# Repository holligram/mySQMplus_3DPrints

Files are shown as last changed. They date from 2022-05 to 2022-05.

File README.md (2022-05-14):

# mySQM+ 3DPrints

Unofficial 3D prints designed to work with the [mySQM+ DIY SQM WEATHER STATION](https://sourceforge.net/projects/mysqmproesp32/files) project by Robert Brown.

These prints will be installed outdoors to monitor weather and will be subjected to the elements over time. The recommend material for 3D printing is ASA or PETG, both of which are insensitive to changing temperature and are resistant to UV rays. The UV resistance is key to choosing one of these materials. 

## Anemometer

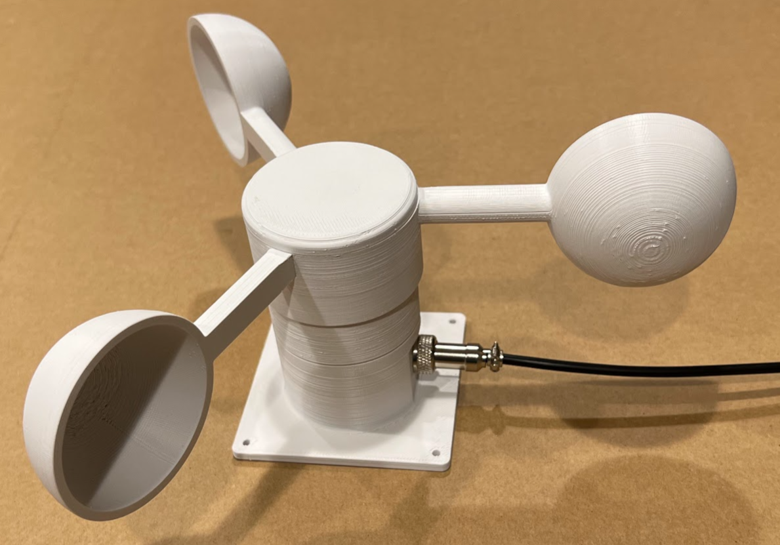
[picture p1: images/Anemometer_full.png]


[More Info on the Anemometer](3D%20Prints%20(STL)/Anemometer)

## Wind Vane

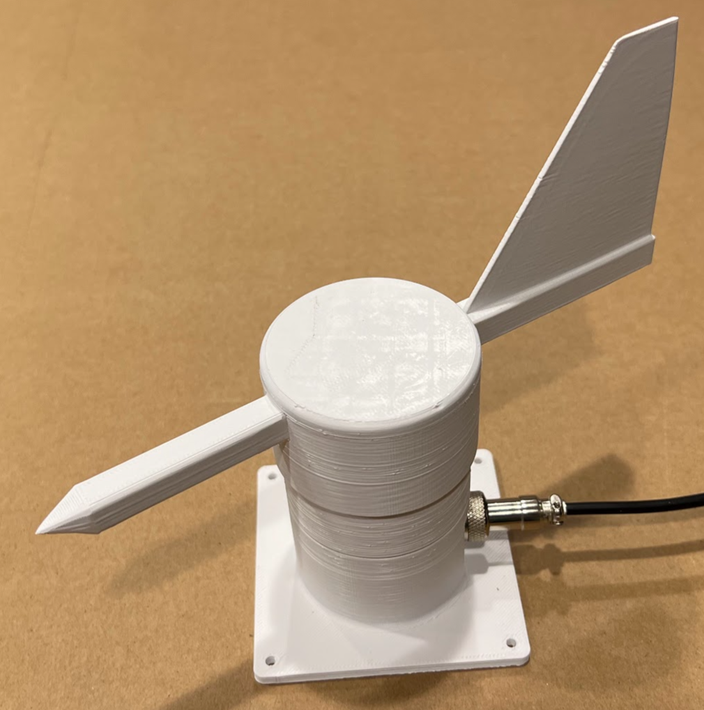
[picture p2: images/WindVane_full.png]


[More Info on the Wind Vane](3D%20Prints%20(STL)/Wind%20Vane)

## About

BY: Graham Hollis [holligram](https://github.com/holligram)

LICENSE: Creative Commons Zero v1.0 Universal

ATTRIBUTE: This is a redesign of the mySQM+ 3D prints created by Robert Brown for his mySQM+ DIY SQM WEATHER STATION project found on Sourceforge at the link https://sourceforge.net/projects/mysqmproesp32/files

Incorporating the threaded joint idea from the rework of Robert Brown's anemometer design that was made by [CBaker007](https://github.com/CBaker007/mySQM-3D_Anemometer/)

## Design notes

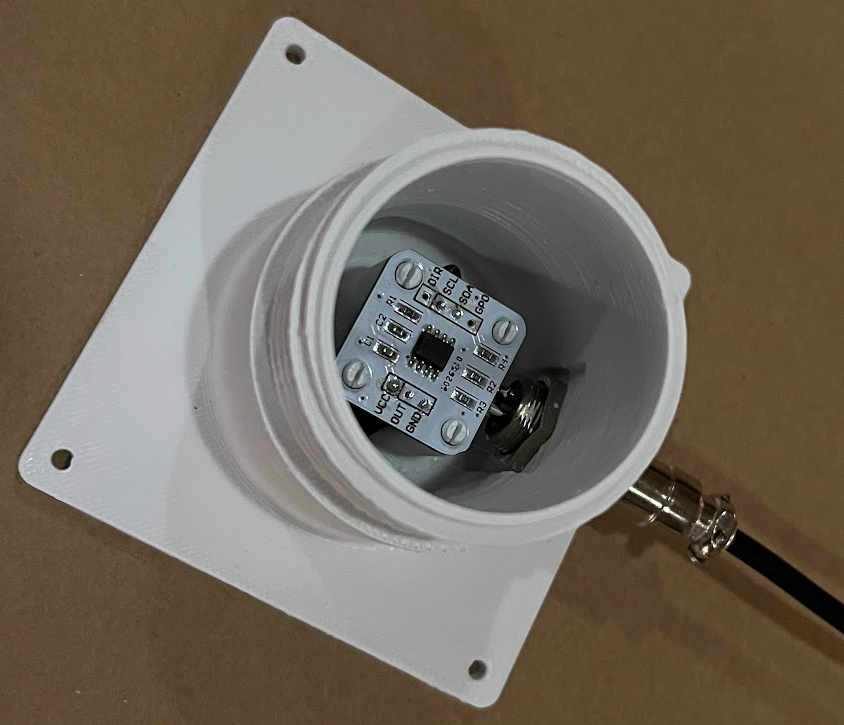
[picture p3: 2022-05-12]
images/WindVane_base.png

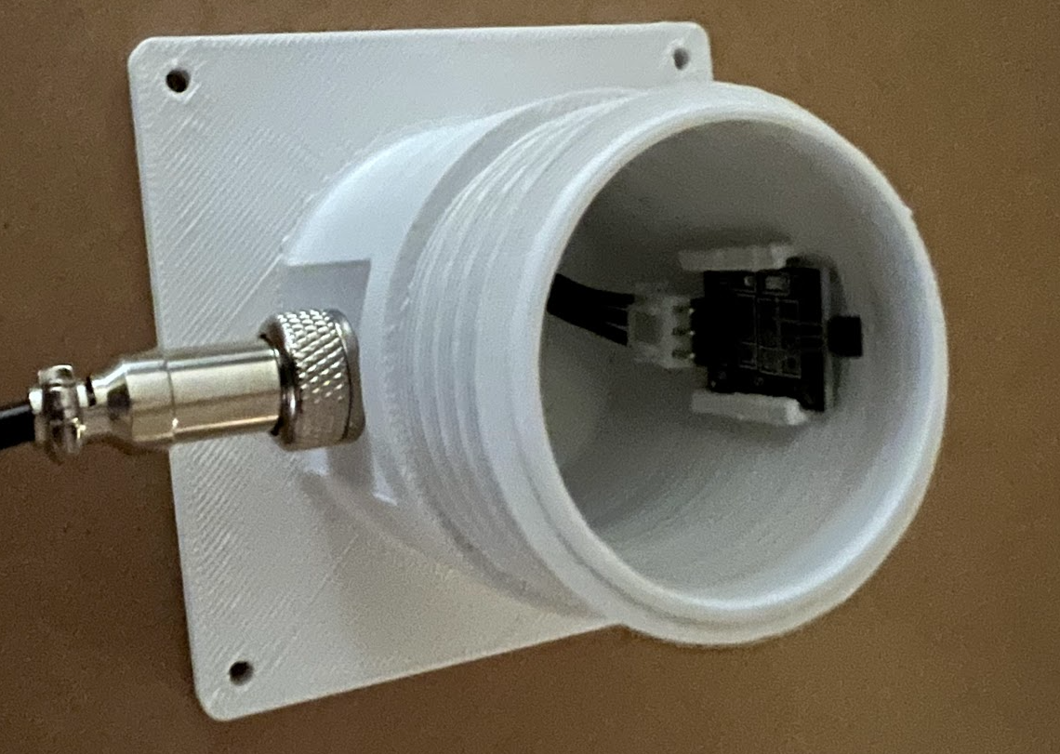
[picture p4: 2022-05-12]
images/Anemometer_base.png

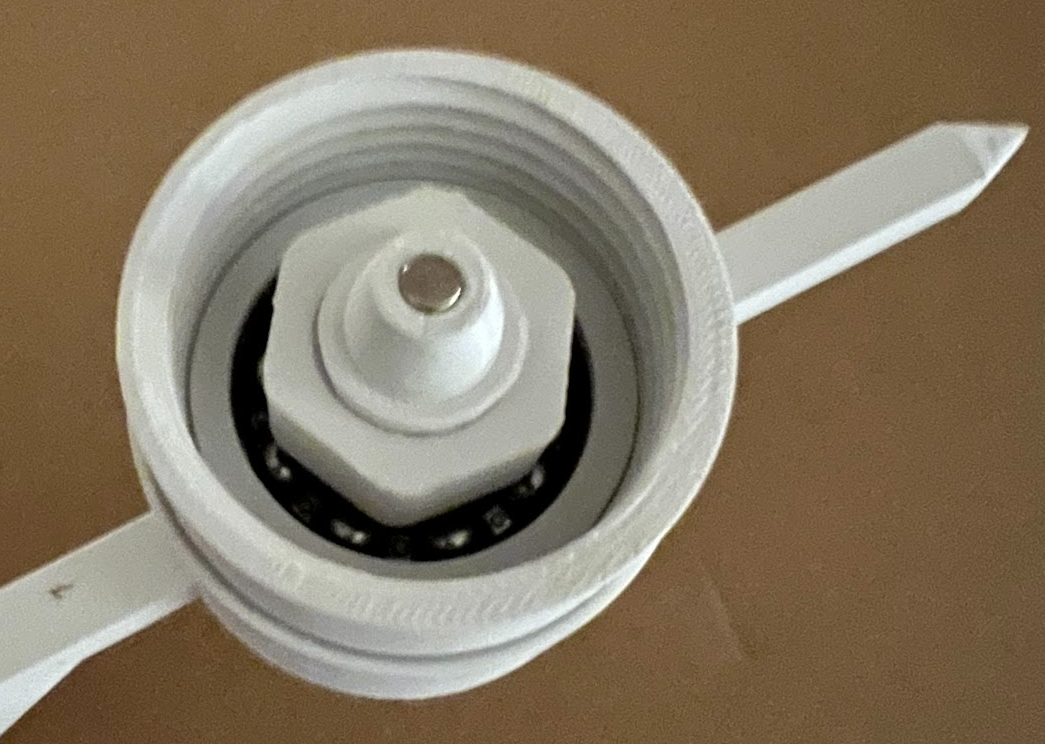
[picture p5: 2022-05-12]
images/WindVane_top.png

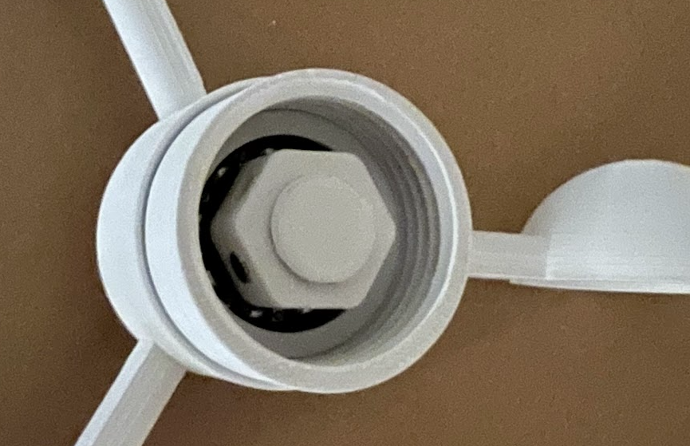
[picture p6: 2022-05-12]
images/Anemometer_top.png

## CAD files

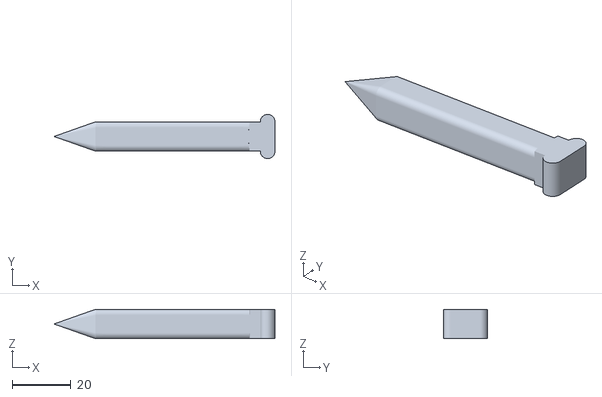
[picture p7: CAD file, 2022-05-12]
3D Prints (STL)/Wind Vane/Pointer.stl
75.0 x 15.0 x 10.0

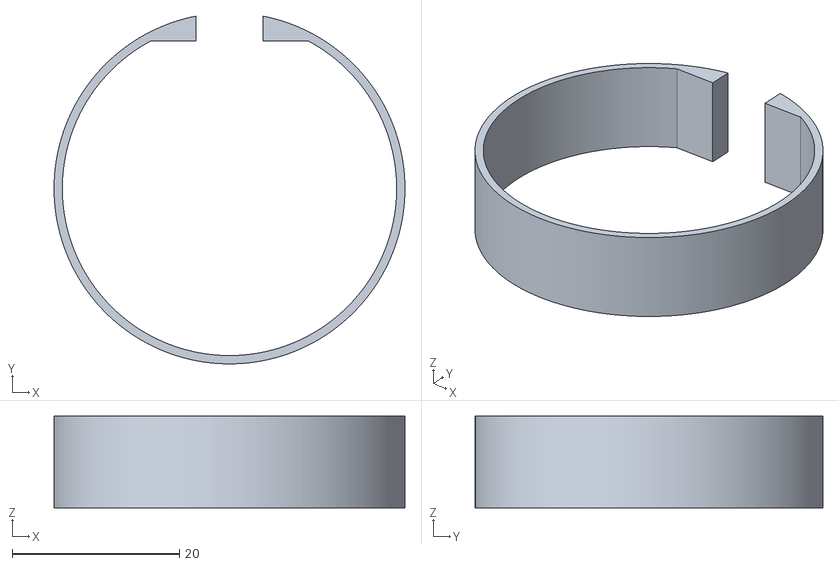
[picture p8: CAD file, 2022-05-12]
3D Prints (STL)/Anemometer/Board Retainer.stl
42.0 x 41.6 x 11.0

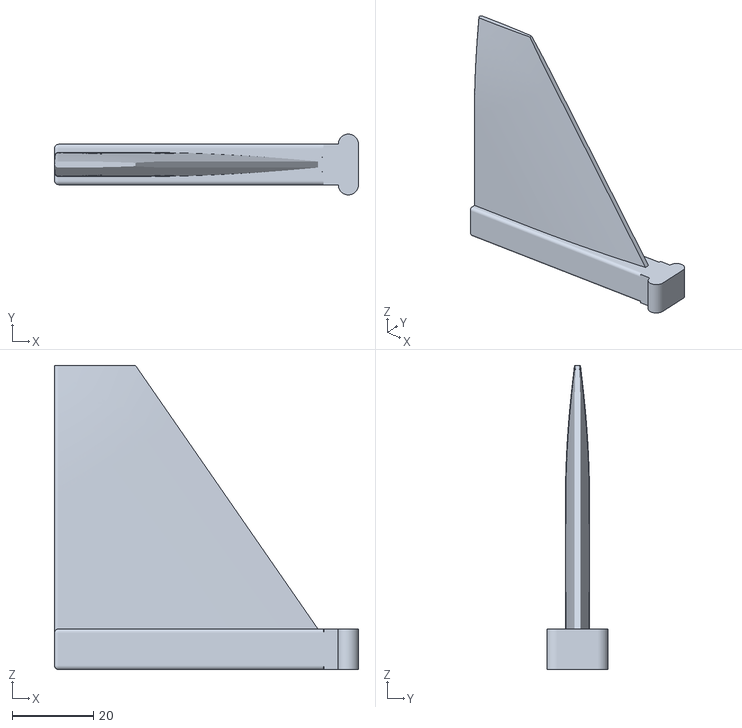
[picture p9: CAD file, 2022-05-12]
3D Prints (STL)/Wind Vane/Tail.stl
75.0 x 15.0 x 75.0

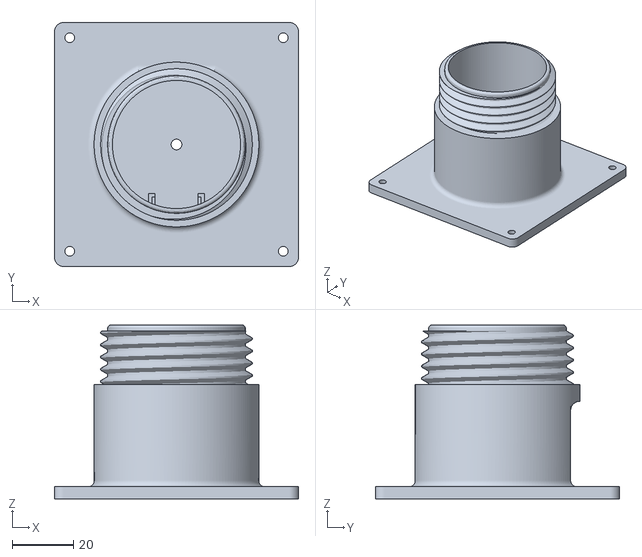
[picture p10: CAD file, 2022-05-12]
3D Prints (STL)/Anemometer/Base_KY-003.stl
80.0 x 80.0 x 57.0

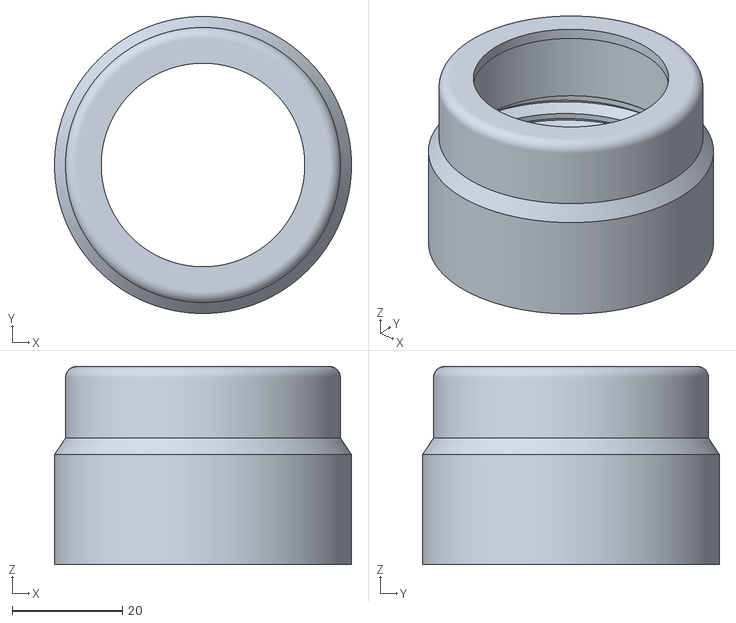
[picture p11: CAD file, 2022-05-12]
3D Prints (STL)/Wind Vane/Bearing Housing.stl
54.0 x 54.0 x 36.0

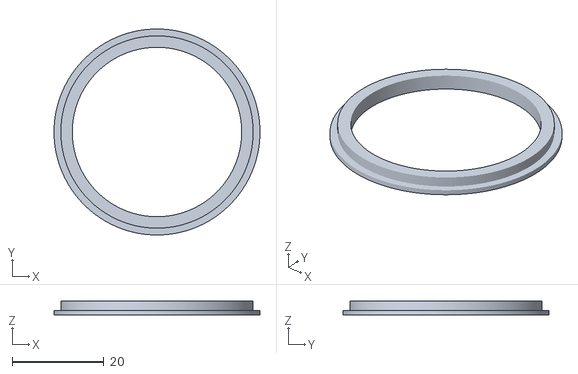
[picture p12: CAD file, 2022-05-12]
3D Prints (STL)/Anemometer/Bearing Retainer.stl
45.0 x 45.0 x 3.00

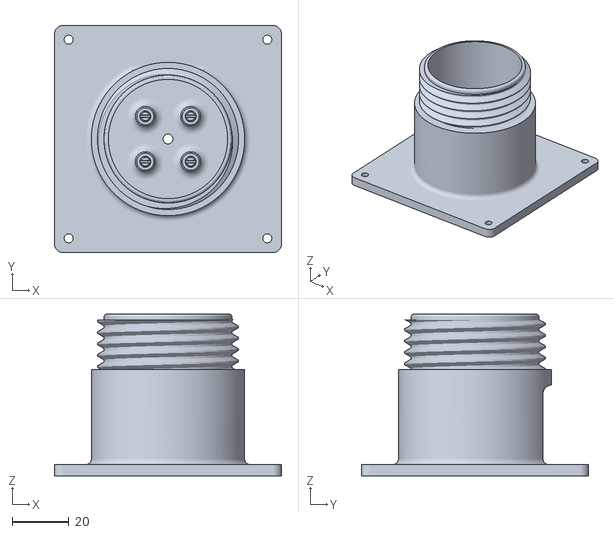
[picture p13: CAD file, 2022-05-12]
3D Prints (STL)/Wind Vane/Base.stl
80.0 x 80.0 x 57.0

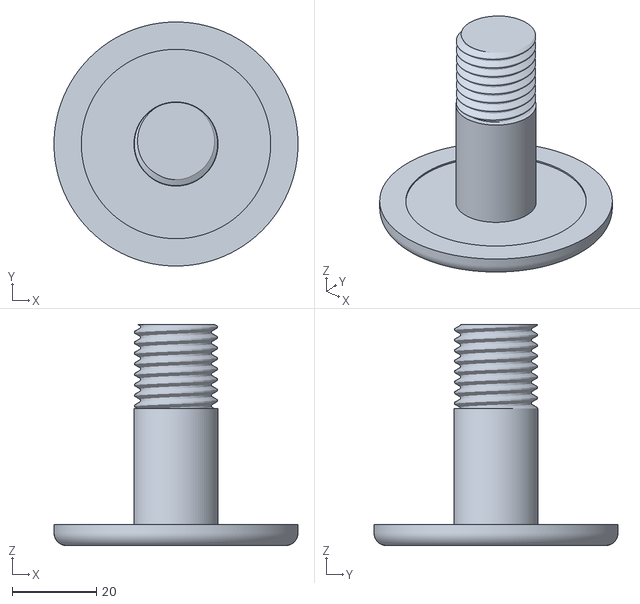
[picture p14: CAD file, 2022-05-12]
3D Prints (STL)/Anemometer/Cap.stl
58.0 x 58.0 x 52.6

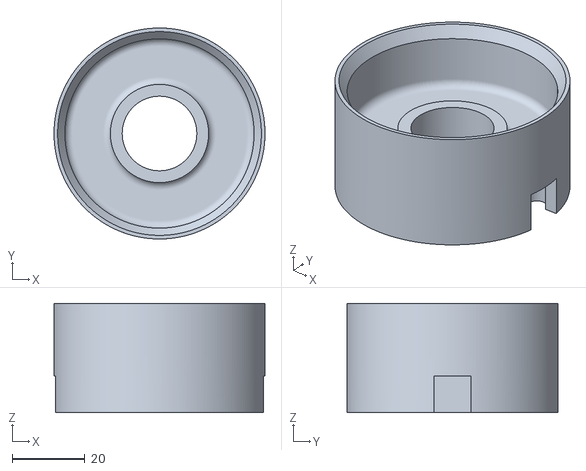
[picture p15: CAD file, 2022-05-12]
3D Prints (STL)/Wind Vane/Hub.stl
58.0 x 58.0 x 30.0

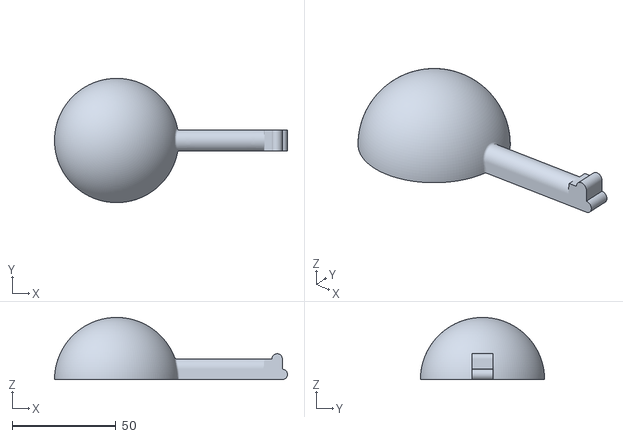
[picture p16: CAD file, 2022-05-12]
3D Prints (STL)/Anemometer/Arm.stl
112.5 x 60.0 x 30.0

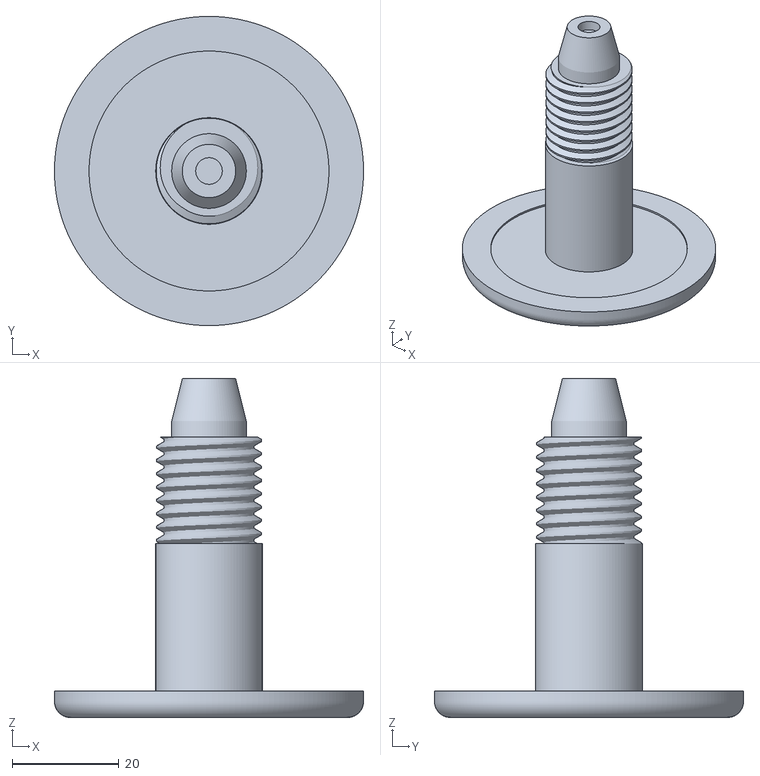
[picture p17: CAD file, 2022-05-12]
3D Prints (STL)/Wind Vane/Cap.stl
58.0 x 58.0 x 63.6

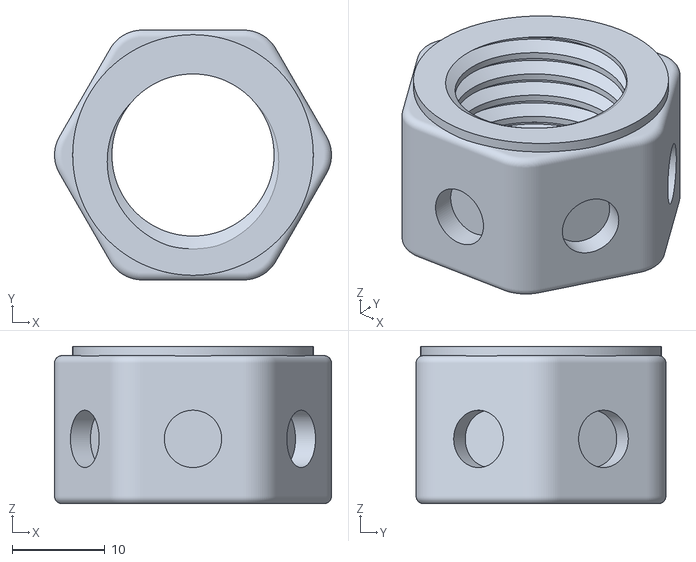
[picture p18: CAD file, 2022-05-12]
3D Prints (STL)/Anemometer/Nut.stl
29.9 x 27.0 x 17.0

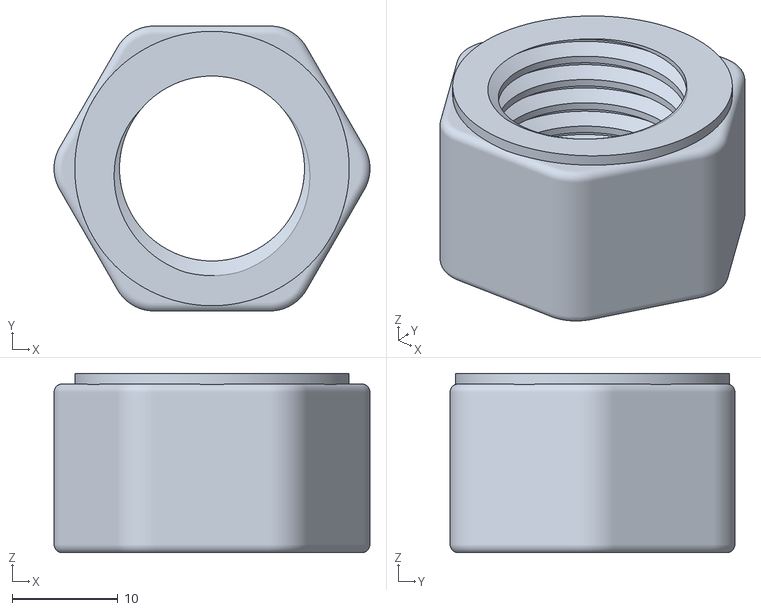
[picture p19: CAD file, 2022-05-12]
3D Prints (STL)/Wind Vane/Nut.stl
29.9 x 27.0 x 17.0

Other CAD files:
3D Prints (STL)/Anemometer/Base_KY-024.stl
3D Prints (STL)/Wind Vane/Retainer.stl
3D Prints (STL)/Anemometer/Bearing Housing.stl
3D Prints (STL)/Anemometer/Hub.stl
CAD (Fusion)/Anemometer.f3d
CAD (Fusion)/Wind Vane.f3d

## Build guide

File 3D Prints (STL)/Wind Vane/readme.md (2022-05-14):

## Wind Vane

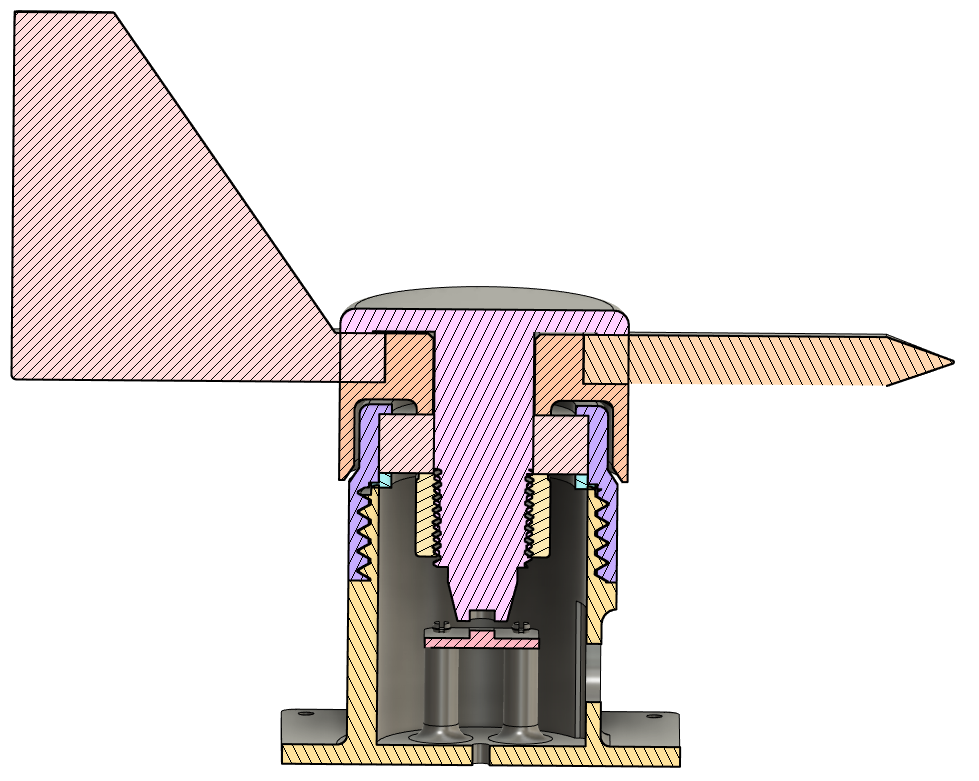
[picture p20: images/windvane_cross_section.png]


### Features

* A key feature of this design is that it does not use any metal fasteners to assemble. There are four 3d printed threads that are integral to the design and make for a secure assembly. As these are functional prints, they all should be printed with a maximum layer height of 0.2mm, 4 walls in and out, as well as 4 top and bottom layers.
* The sensor used is the AS5600 magnetic angle sensor. The bottom of base has four pinch pins that secure the sensor in place. Once assembled, the sensor will be at the correct height just below the magnet.

### Bill of Materials
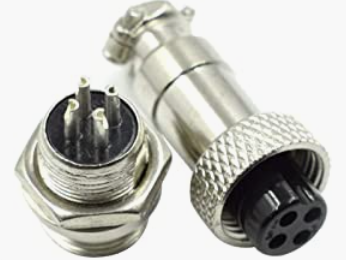
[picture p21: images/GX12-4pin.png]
-  4 pin Aviation type (GX12) connectors 
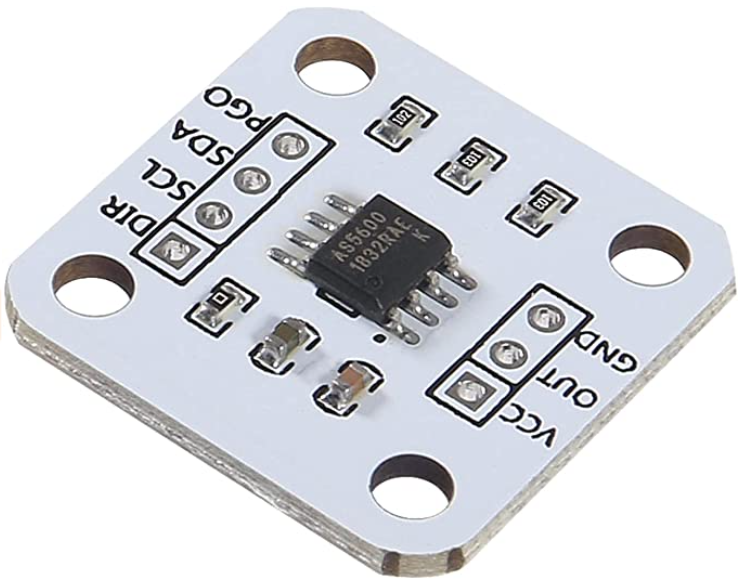
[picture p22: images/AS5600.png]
- AS5600 magnetic angle sensor with magnet.
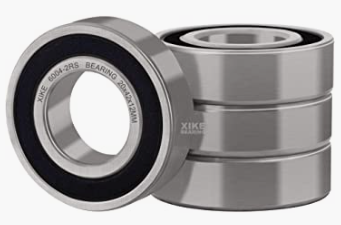
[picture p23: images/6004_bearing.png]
- 6004 bearing 20x42x12mm 

### Notes
- The common 6x3mm project magnet is too strong for this sensor and may overpower it causing unreliable data. I recommend using the smaller magnet provided with the sensor.
- Be sure the magnet is securely held in the provided cavity of the cap. Should it drop out and fall on the sensor below it, it may cause the magic smoke to escape the ESP32. Ask me how I know this!
- The pointer and tail are a tight fit in the hub which are then held fast by the cap. There may need some gentle filing to get them to fit correctly into the hub depending on how accurate your 3D printer is and how much over extrusion you have.
- The 3D printed threads may need to touched up with a file depending on how well your printer reproduces these.
- Prepare the bearing by removing and discarding the seals on both sides. You can pry underneath the plastic and lift them off. You will then need to wash out all the factory grease using a solvent. Once all the grease has been dissolved, it's dry and spins freely, lubricate with one drop of light machine oil.

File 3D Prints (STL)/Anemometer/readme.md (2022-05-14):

## Anemometer

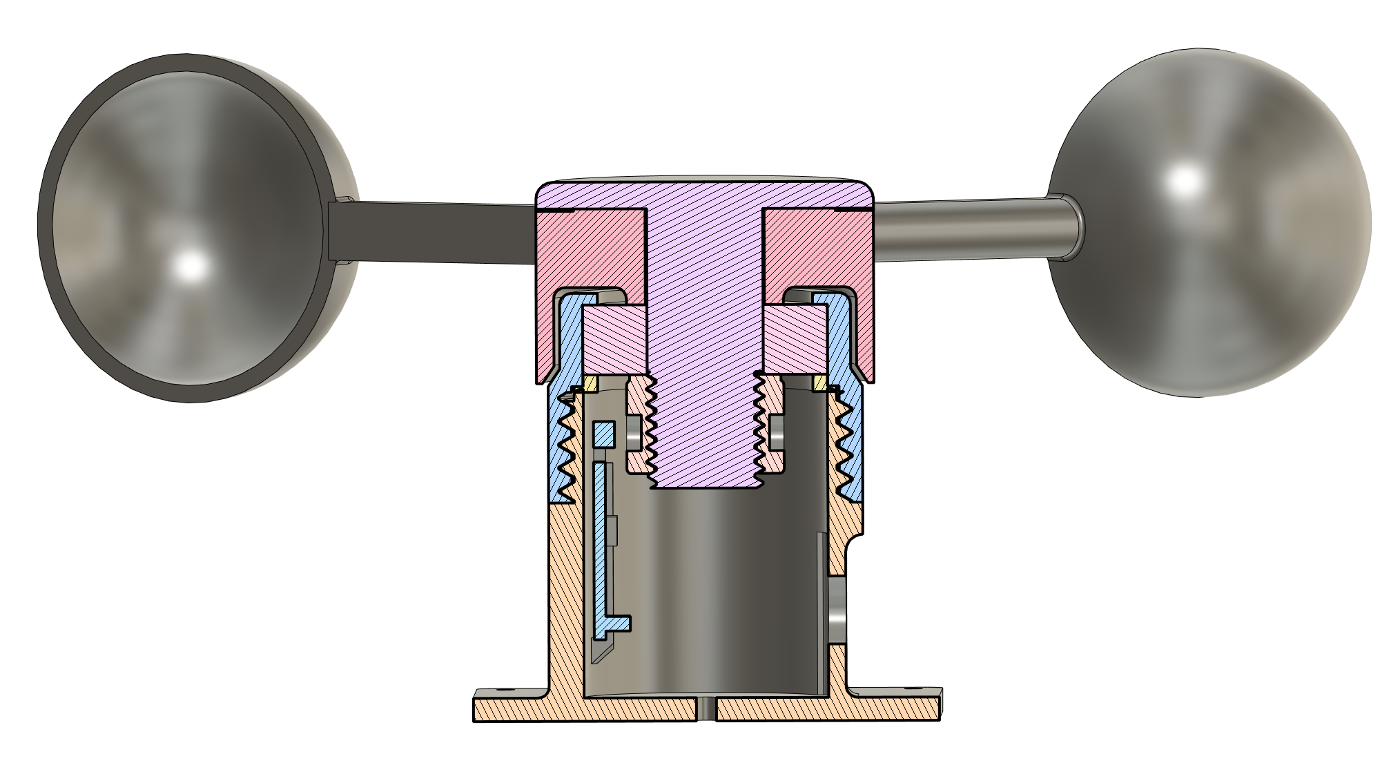
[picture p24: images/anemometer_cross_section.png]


### Features

* A key feature of this design is that it does not use any metal fasteners to assemble. There are four 3d printed threads that are integral to the design and make for a secure assembly. As these are functional prints, they all should be printed with a maximum layer height of 0.2mm, 4 walls in and out, as well as 4 top and bottom layers.

* The Anemometer design has an arm length of 100mm from the center of the hub to the middle of the cup. The mySQM+ mydefines.h will need to be adjusted:

`#define ARM_LENGTH                  (0.100)`

* The sensor used is either the KY-024 or the KY-003. The base has a pocket to accommodate the sensor and which places the magnet hall sensor at the correct height to interact with the magnets, which are housed in the hub nut. There are two versions of the base stl's provided. Select the one that matches the sensor you plan to use.
* There is an optional board retainer ring which will keep the board securely held in the pocket.  
* The 3D printed nut doubles as the magnet carrier and can contain either 1, 2, 3, or 6 magnets. Two magnets are recommended. The number of pulses generated per revolution is based on 1 pulse per magnet. The mySQM+ mydefines.h will need to be adjusted based on the number of magnets you use:

`#define PULSES_PER_REVOLUTION       2`

### Bill of Materials
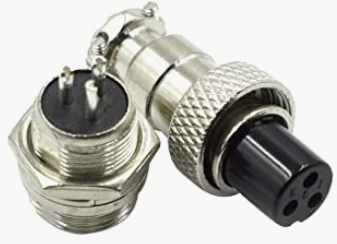
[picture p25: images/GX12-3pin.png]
-  3 pin Aviation type (GX12) connectors 
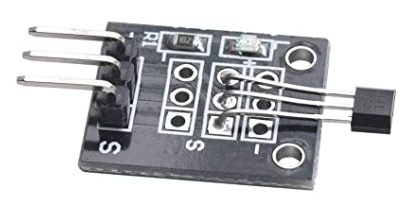
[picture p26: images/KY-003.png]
- KY-024 module <b>&nbsp;&nbsp;&nbsp;OR&nbsp;&nbsp;&nbsp;</b> KY-003 module
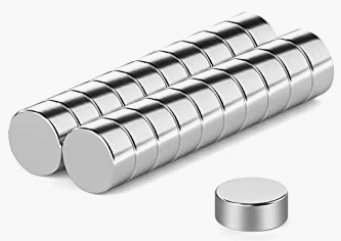
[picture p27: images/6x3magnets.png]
- 6mmx3mm magnets
- 6004 bearing 20x42x12mm 

### Notes
- I've tried both the KY-024 and the KY-003 module and was not able to get the KY-024 to work correctly.
- The KY-003 module works perfectly without the D2 or R3 components present in the circuit. Refer the mySQM+ documentation for more detail on this.
- The arms are a tight fit in the hub which are then held fast by the cap. The ends of the arms may need some filing to get them to fit into the hub depending on how accurate your 3D printer is and how much over extrusion you have.
- The 3D printed threads may need to touched up with a file depending on how well your printer reproduces these.
- Prepare the bearing by removing and discarding the seals on both sides. You can pry underneath the plastic and lift them off. You will then need to wash out all the factory grease using a solvent. Once all the grease has been dissolved, it's dry and spins freely, lubricate with one drop of light machine oil.
